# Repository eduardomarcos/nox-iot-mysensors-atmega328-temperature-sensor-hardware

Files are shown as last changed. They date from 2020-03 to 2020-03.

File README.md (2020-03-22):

# Arduino Atmega 328 RF Temperature and Humidity Sensor 

## Custom temperature and humidity sensor using an atmega 328 PU as CPU and NRF24L01 as radio to send data over RF using MySensors framework.

_Currently working to make the PCB valid for this enclosure:_

https://es.aliexpress.com/item/32901643453.html

The hardware is the following:

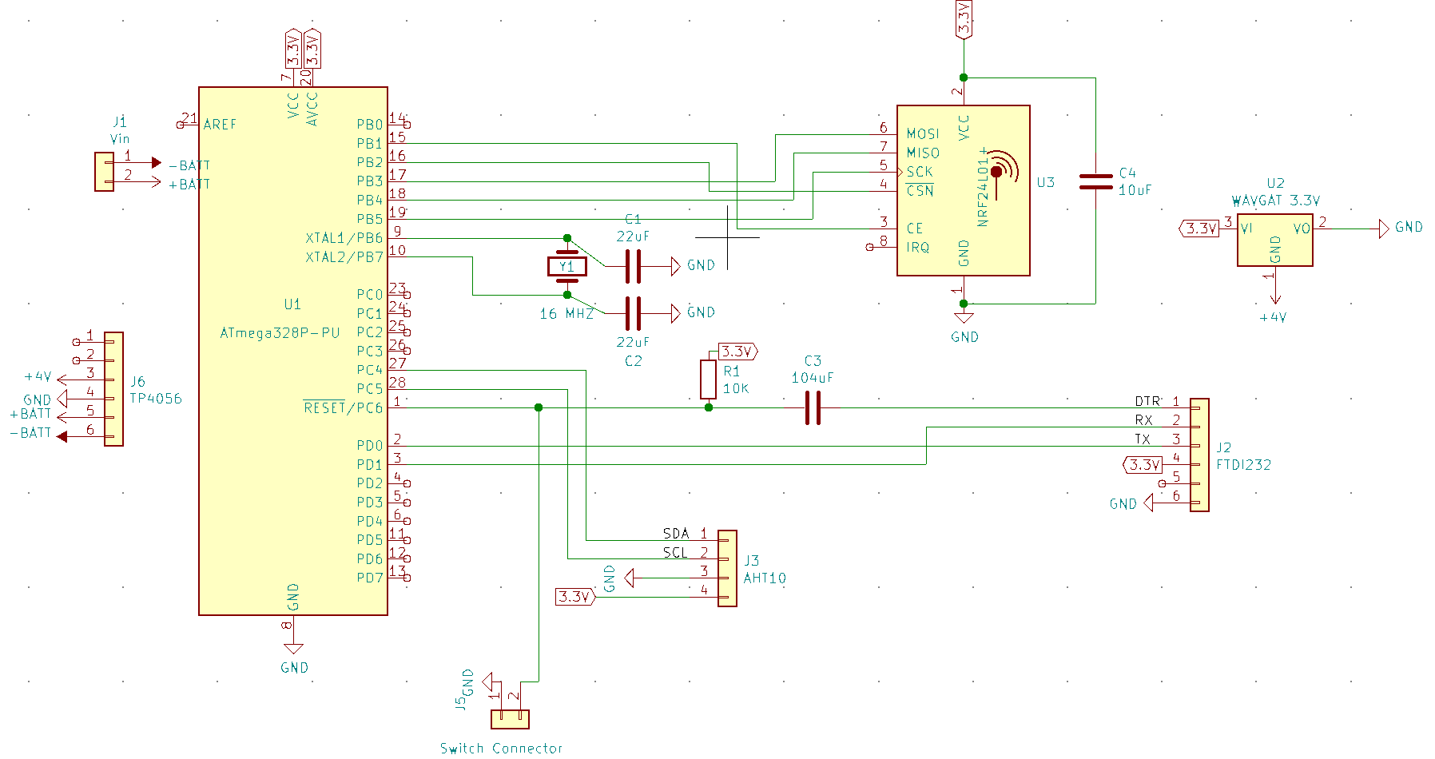
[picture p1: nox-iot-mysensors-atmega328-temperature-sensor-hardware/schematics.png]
Schematics


And this is the current PCB:

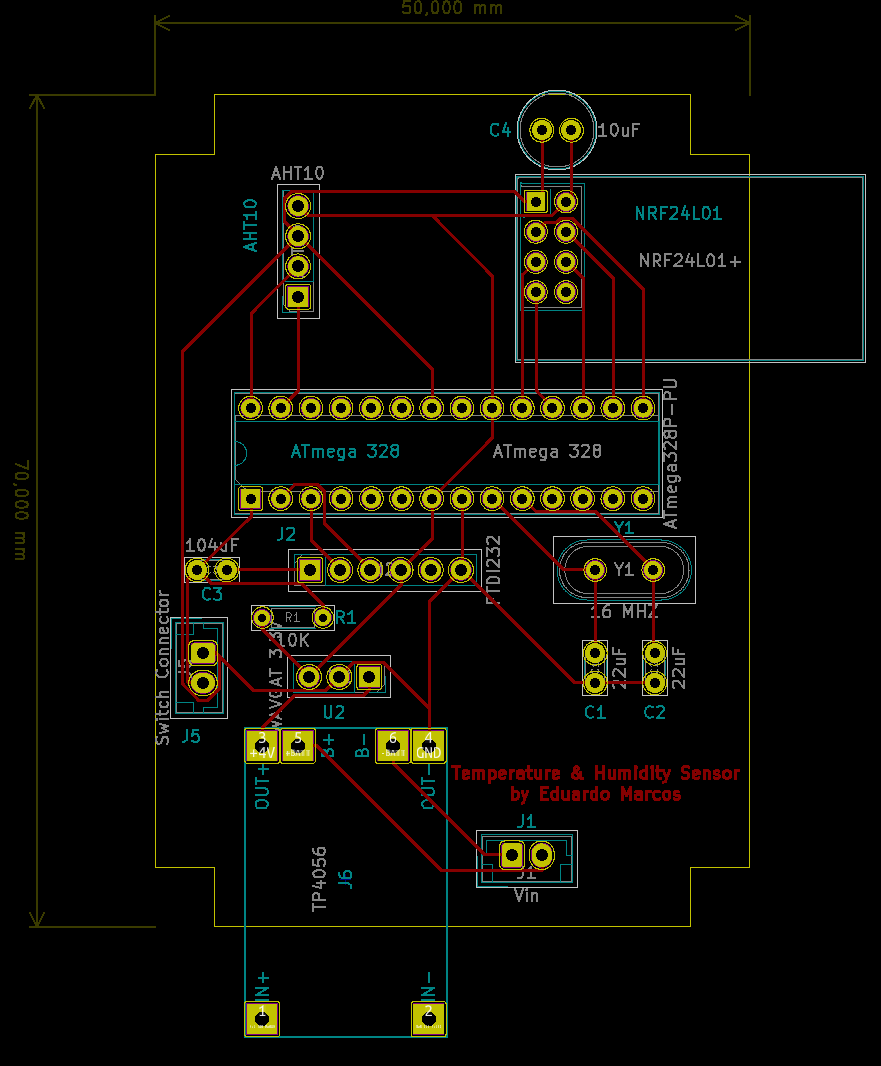
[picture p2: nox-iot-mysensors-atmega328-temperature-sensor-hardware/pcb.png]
PCB


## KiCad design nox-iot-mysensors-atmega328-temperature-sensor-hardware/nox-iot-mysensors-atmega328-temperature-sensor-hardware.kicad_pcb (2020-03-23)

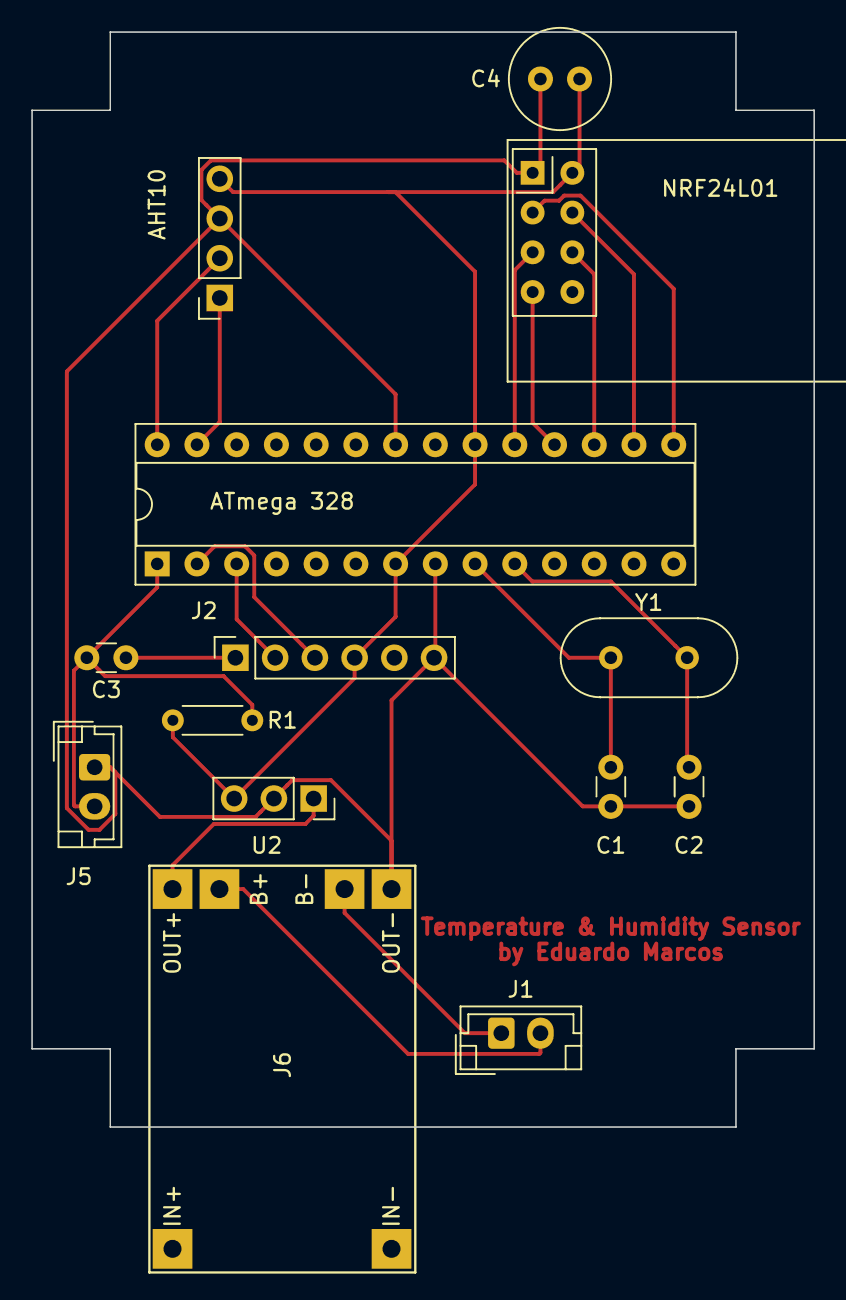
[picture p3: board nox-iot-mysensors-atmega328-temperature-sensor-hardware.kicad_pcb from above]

Board: 2 copper layers, 50.0 x 70.0 mm, 14 parts (0 on the bottom side), 18 nets.

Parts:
AHT10: AHT10; PinSocket_1x04_P2.54mm_Vertical
ATmega 328: ATmega328P-PU; DIP-28_W7.62mm_Socket
C1, C2: 22uF; C_Disc_D3.0mm_W1.6mm_P2.50mm
C3: 104uF; C_Disc_D3.0mm_W1.6mm_P2.50mm
C4: 10uF; C_Radial_D6.3mm_H5.0mm_P2.50mm
J1: Vin; JST_EH_B2B-EH-A_1x02_P2.50mm_Vertical
J2: FTDI232; PinSocket_1x06_P2.54mm_Vertical
J5: Switch Connector; JST_EH_B2B-EH-A_1x02_P2.50mm_Vertical
J6: TP4056
NRF24L01: NRF24L01+; nRF24L01_Breakout
R1: 10K; R_Axial_DIN0204_L3.6mm_D1.6mm_P5.08mm_Horizontal
U2: WAVGAT 3.3V; PinSocket_1x03_P2.54mm_Vertical
Y1: 16 MHZ; Crystal_HC49-U_Vertical

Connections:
3.3V: AHT10.4, ATmega 328.7, ATmega 328.20, C4.1, J2.4, NRF24L01.2, R1.1, U2.3
+4V: J6.3, U2.1
+BATT: J1.2, J6.5
-BATT: J1.1, J6.6
/DTR: C3.1, J2.1
/RX: ATmega 328.3, J2.2
/SCL: AHT10.2, ATmega 328.28
/SDA: AHT10.1, ATmega 328.27
/TX: ATmega 328.2, J2.3
GND: AHT10.3, ATmega 328.8, ATmega 328.22, C1.1, C2.1, C4.2, J2.6, J5.1, J6.4, NRF24L01.1, U2.2
unnamed: ATmega 328.9, C1.2, Y1.1
unnamed: ATmega 328.10, C2.2, Y1.2
unnamed: ATmega 328.1, C3.2, J5.2, R1.2
unnamed: ATmega 328.15, NRF24L01.3
unnamed: ATmega 328.16, NRF24L01.4
unnamed: ATmega 328.17, NRF24L01.6
unnamed: ATmega 328.18, NRF24L01.7
unnamed: ATmega 328.19, NRF24L01.5

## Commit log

2020-03-21 temperature sensor schema
    [nox-iot-mysensors-atmega328-temperature-sensor-hardware.kicad_pcb, nox-iot-mysensors-atmega328-temperature-sensor-hardware.sch]
2020-03-21 pcb first attemp
    [nox-iot-mysensors-atmega328-temperature-sensor-hardware.kicad_pcb]
2020-03-21 aht10 sensor instead of dht11 and 3.3v boost
    [nox-iot-mysensors-atmega328-temperature-sensor-hardware.kicad_pcb, nox-iot-mysensors-atmega328-temperature-sensor-hardware.sch]
2020-03-21 components in place
    before wiring components por perfboard
    [nox-iot-mysensors-atmega328-temperature-sensor-hardware.kicad_pcb, nox-iot-mysensors-atmega328-temperature-sensor-hardware.sch, perfboard.fzz]
2020-03-21 wires complete for perfboard
    [nox-iot-mysensors-atmega328-temperature-sensor-hardware.kicad_pcb, nox-iot-mysensors-atmega328-temperature-sensor-hardware.sch]
2020-03-21 adjust to 10uF the NRF24L01 capacitor
    [nox-iot-mysensors-atmega328-temperature-sensor-hardware.kicad_pcb, nox-iot-mysensors-atmega328-temperature-sensor-hardware.sch, perfboard.fzz]
2020-03-21 change switch button to switch connector
    [nox-iot-mysensors-atmega328-temperature-sensor-hardware.kicad_pcb, nox-iot-mysensors-atmega328-temperature-sensor-hardware.sch]
2020-03-22 upload schematics and pcb images
2020-03-22 update readme with images
    [nox-iot-mysensors-atmega328-temperature-sensor-hardware.sch]
2020-03-23 updated with proper pcb
    [nox-iot-mysensors-atmega328-temperature-sensor-hardware.kicad_pcb, nox-iot-mysensors-atmega328-temperature-sensor-hardware.sch]
2020-03-23 ignore gerber files
